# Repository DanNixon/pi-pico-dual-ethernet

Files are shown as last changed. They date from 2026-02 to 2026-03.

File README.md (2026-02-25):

# Pi Pico Dual Ethernet

Pi Pico x 2 W5500 driven Ethernet interfaces (one of which is PoE).

Designed with the intention of being a IO/OT gateway for a CNC machine.
May actually have other uses.

Pinout can be found in the [demo firmware](./demo-firmware/src/main.rs).

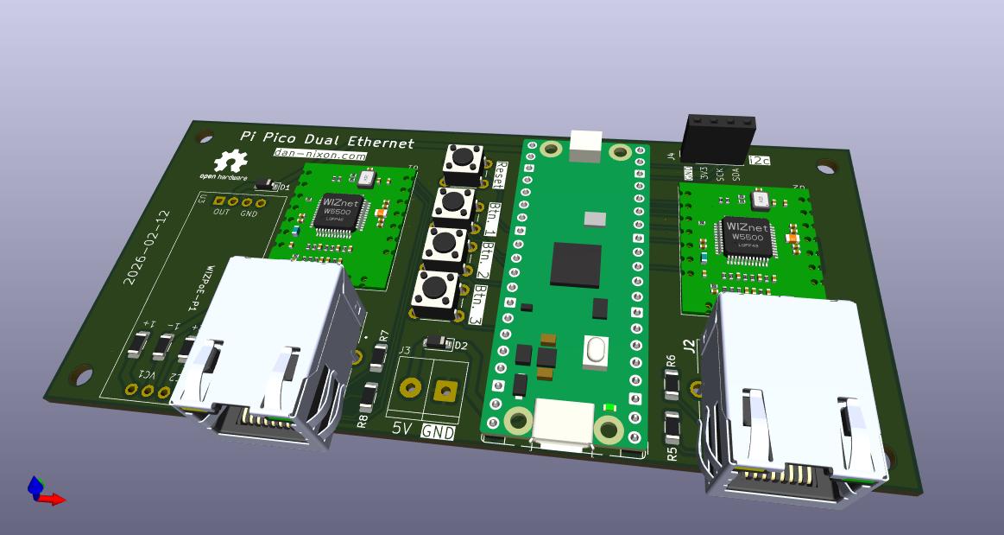
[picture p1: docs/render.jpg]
CAD render of PCB


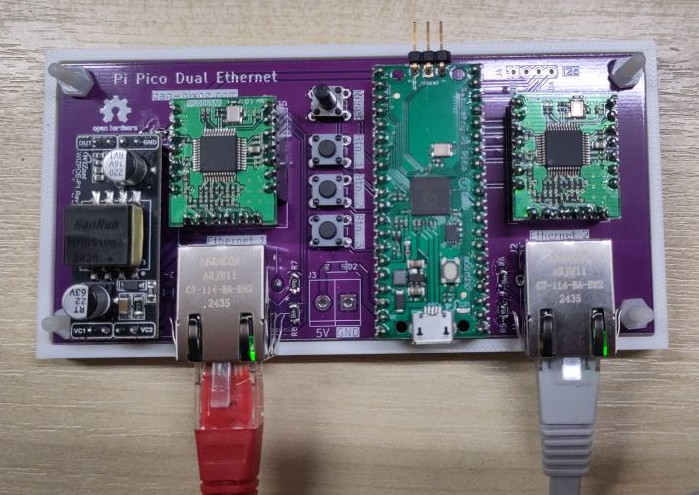
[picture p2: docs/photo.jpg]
Photo of assembled PCB


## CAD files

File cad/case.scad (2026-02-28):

board_size = [118, 56] + [1, 1];
mount_size = board_size + [5, 5];
height = 8;

pcb_thickness = 1.6;

screw_centres = [110, 48];
screw_positions = [
  [screw_centres[0] / 2, screw_centres[1] / 2],
  [-screw_centres[0] / 2, screw_centres[1] / 2],
  [screw_centres[0] / 2, -screw_centres[1] / 2],
  [-screw_centres[0] / 2, -screw_centres[1] / 2],
];

module Case() {
  tray_depth = 4;

  difference() {
    union() {
      difference() {
        translate([0, 0, -height]) {
          linear_extrude(height) {
            square(mount_size, center = true);
          }
        }

        translate([0, 0, 0.01 - tray_depth]) {
          linear_extrude(tray_depth) {
            square(board_size, center = true);
          }
        }
      }

      translate([0, 0, -tray_depth]) {
        for(p = screw_positions) {
          translate(p) {
            cylinder(d = 8, h = abs(tray_depth) - pcb_thickness);
          }
        }
      }
    }

    translate([0, 0, -height - 1]) {
      for(p = screw_positions) {
        translate(p) {
          cylinder(d = 4, h = height + 2);
        }
      }
    }
  }
}

module DinBracketMount() {
  h2 = 6;
  depth = 30;
  fw = 1.8;
  ho = 3.7;

  difference() {
    translate([0, 0, -height - h2]) {
      linear_extrude(h2) {
        square(mount_size, center = true);
      }
    }

    translate([0, 0, -height - h2 - 0.01]) {
      for(p = screw_positions) {
        translate(p) {
          cylinder(d = 4, h = h2 + 0.1);
        }
      }

      o = -(mount_size[1] / 2) + 12;
      for(y = [o, o + 38]) {
        translate([0, y, ho]) {
          for(a = [0, 180]) {
            rotate([0, 0, a]) {
              translate([(mount_size[0] / 2) - depth + 0.1, 0, 0]) {
                rotate([0, 90, 0])
                cylinder(d = 4, h = depth, $fn = 9);
              }
              translate([(mount_size[0] / 2) - depth + 0.1, -fw / 2, -ho]) {
                cube([depth, fw, ho]);
              }
            }
          }
        }
      }
    }
  }
}

Case();
DinBracketMount();

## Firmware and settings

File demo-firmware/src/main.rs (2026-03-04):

#![no_std]
#![no_main]

mod buttons;
mod display;
mod network;
mod wall_time;

use defmt::{info, warn};
use defmt_rtt as _;
use embassy_executor::Spawner;
use embassy_net::Stack;
use embassy_rp::{Peri, peripherals};
use embassy_sync::{
    blocking_mutex::raw::CriticalSectionRawMutex, channel::Channel, pubsub::WaitResult,
};
use embassy_time::{Duration, Timer};
use embedded_io_async::Write;
use heapless::Vec;
use panic_probe as _;
use portable_atomic as _;

assign_resources::assign_resources! {
    // Ethernet 1 is the same pins as the WIZnet evaluation boards
    ethernet_1: Ethernet1Resources {
        miso: PIN_16,
        mosi: PIN_19,
        clk: PIN_18,
        spi: SPI0,
        tx_dma: DMA_CH0,
        rx_dma: DMA_CH1,
        cs_pin: PIN_17,
        int_pin: PIN_21,
        rst_pin: PIN_20,
    },
    ethernet_2: Ethernet2Resources {
        miso: PIN_8,
        mosi: PIN_11,
        clk: PIN_10,
        spi: SPI1,
        tx_dma: DMA_CH2,
        rx_dma: DMA_CH3,
        cs_pin: PIN_9,
        int_pin: PIN_13,
        rst_pin: PIN_12,
    },
    display: DisplayResources {
        i2c: I2C1,
        sda: PIN_14,
        scl: PIN_15,
    },
    buttons: ButtonResources {
        user_1: PIN_22,
        user_2: PIN_26,
        user_3: PIN_28,
    },
}

#[embassy_executor::main]
async fn main(spawner: Spawner) {
    let p = embassy_rp::init(Default::default());
    let r = split_resources!(p);

    spawner.must_spawn(display::task(r.display));

    spawner.must_spawn(say_button_task());
    buttons::init(r.buttons, spawner);

    let net_stack_1 = network::init_ethernet_1(r.ethernet_1, spawner).await;
    let net_stack_2 = network::init_ethernet_2(r.ethernet_2, spawner).await;

    spawner.must_spawn(say_time_task());
    spawner.must_spawn(wall_time::ntp_task(net_stack_2));

    spawner.must_spawn(listen_task(net_stack_1, 0, 1234));
    spawner.must_spawn(listen_task(net_stack_1, 1, 1234));

    spawner.must_spawn(repeat_task(net_stack_2, 1234));
}

#[embassy_executor::task]
async fn say_button_task() -> ! {
    let mut subscriber = buttons::BUTTON_EVENTS.subscriber().unwrap();

    loop {
        match subscriber.next_message().await {
            WaitResult::Lagged(_) => {
                unreachable!();
            }
            WaitResult::Message(event) => {
                info!("Button: {}", event);
            }
        }
    }
}

#[embassy_executor::task]
async fn say_time_task() -> ! {
    loop {
        info!("Wall clock: {}", wall_time::now());
        Timer::after_secs(1).await;
    }
}

static CHANNEL: Channel<CriticalSectionRawMutex, Vec<u8, 256>, 8> = Channel::new();

#[embassy_executor::task(pool_size = 2)]
async fn listen_task(stack: Stack<'static>, id: u8, port: u16) -> ! {
    let mut rx_buffer = [0; 4096];
    let mut tx_buffer = [0; 4096];
    let mut buf = [0; 4096];
    loop {
        let mut socket = embassy_net::tcp::TcpSocket::new(stack, &mut rx_buffer, &mut tx_buffer);
        socket.set_timeout(Some(Duration::from_secs(10)));

        info!("SOCKET {}: Listening on TCP:{}...", id, port);
        if let Err(e) = socket.accept(port).await {
            warn!("accept error: {:?}", e);
            continue;
        }
        info!(
            "SOCKET {}: Received connection from {:?}",
            id,
            socket.remote_endpoint()
        );

        loop {
            let n = match socket.read(&mut buf).await {
                Ok(0) => {
                    warn!("read EOF");
                    break;
                }
                Ok(n) => n,
                Err(e) => {
                    warn!("SOCKET {}: {:?}", id, e);
                    break;
                }
            };
            info!(
                "SOCKET {}: rxd {}",
                id,
                core::str::from_utf8(&buf[..n]).unwrap()
            );

            let vec = Vec::try_from(&buf[..n]).unwrap();
            if CHANNEL.try_send(vec).is_err() {
                warn!("Failed to send on channel");
            }
        }
    }
}

#[embassy_executor::task]
async fn repeat_task(stack: Stack<'static>, port: u16) -> ! {
    let mut rx_buffer = [0; 4096];
    let mut tx_buffer = [0; 4096];

    loop {
        let mut socket = embassy_net::tcp::TcpSocket::new(stack, &mut rx_buffer, &mut tx_buffer);
        socket.set_timeout(Some(Duration::from_secs(10)));

        info!("SOCKET: Listening on TCP:{}...", port);
        if let Err(e) = socket.accept(port).await {
            warn!("accept error: {:?}", e);
            continue;
        }
        info!(
            "SOCKET: Received connection from {:?}",
            socket.remote_endpoint()
        );

        loop {
            let data = CHANNEL.receive().await;

            if let Err(e) = socket.write_all(&data).await {
                warn!("write error: {:?}", e);
                break;
            }
        }
    }
}

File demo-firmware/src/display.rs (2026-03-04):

use crate::{
    DisplayResources,
    network::{ETHERNET_1_CONFIG, ETHERNET_2_CONFIG},
};
use chrono::{Datelike, Timelike};
use core::fmt::Write;
use embassy_rp::{
    bind_interrupts,
    i2c::{I2c, InterruptHandler},
    peripherals::I2C1,
};
use embassy_time::Timer;
use embedded_graphics::{
    Drawable,
    mono_font::{MonoTextStyle, ascii::FONT_6X10},
    pixelcolor::BinaryColor,
    prelude::{Point, Size},
    primitives::Rectangle,
};
use embedded_text::{
    TextBox,
    alignment::HorizontalAlignment,
    style::{HeightMode, TextBoxStyleBuilder},
};
use ssd1306::{
    I2CDisplayInterface, Ssd1306, mode::DisplayConfig, prelude::DisplayRotation,
    size::DisplaySize128x64,
};

#[embassy_executor::task]
pub(crate) async fn task(r: DisplayResources) -> ! {
    let i2c = I2c::new_async(r.i2c, r.scl, r.sda, Irqs, Default::default());

    let interface = I2CDisplayInterface::new(i2c);
    let mut display = Ssd1306::new(interface, DisplaySize128x64, DisplayRotation::Rotate0)
        .into_buffered_graphics_mode();
    display.init().unwrap();

    let character_style = MonoTextStyle::new(&FONT_6X10, BinaryColor::On);
    let textbox_style = TextBoxStyleBuilder::new()
        .height_mode(HeightMode::FitToText)
        .alignment(HorizontalAlignment::Left)
        .paragraph_spacing(2)
        .build();

    let bounds = Rectangle::new(Point::zero(), Size::new(128, 0));

    loop {
        let mut text = heapless::String::<128>::new();

        text.write_str("Rev: ").unwrap();
        text.write_str(git_version::git_version!()).unwrap();
        text.write_char('\n').unwrap();

        let eth_1_config = ETHERNET_1_CONFIG.lock().await.clone();
        text.write_str("IP 1: ").unwrap();
        match eth_1_config {
            Some(config) => text.write_fmt(format_args!("{}\n", config.address)),
            None => text.write_str("none\n"),
        }
        .unwrap();

        let eth_2_config = ETHERNET_2_CONFIG.lock().await.clone();
        text.write_str("IP 2: ").unwrap();
        match eth_2_config {
            Some(config) => text.write_fmt(format_args!("{}\n", config.address)),
            None => text.write_str("none\n"),
        }
        .unwrap();

        let time = crate::wall_time::now();

        text.write_str("Date: ").unwrap();
        match time {
            Some(time) => text.write_fmt(format_args!(
                "{}-{:02}-{:02}\n",
                time.year(),
                time.month(),
                time.day()
            )),
            None => text.write_str("unknown\n"),
        }
        .unwrap();

        text.write_str("Time: ").unwrap();
        match time {
            Some(time) => text.write_fmt(format_args!(
                "{:02}:{:02}:{:02}\n",
                time.hour(),
                time.minute(),
                time.second()
            )),
            None => text.write_str("unknown\n"),
        }
        .unwrap();

        let text_box = TextBox::with_textbox_style(&text, bounds, character_style, textbox_style);

        display.clear_buffer();
        text_box.draw(&mut display).unwrap();
        display.flush().unwrap();

        Timer::after_secs(1).await;
    }
}

bind_interrupts!(struct Irqs {
    I2C1_IRQ => InterruptHandler<I2C1>;
});
